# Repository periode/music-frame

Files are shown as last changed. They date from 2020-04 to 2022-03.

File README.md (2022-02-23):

# music frame

endless music box. wip.

## intent

it is a generative sonic atmosphere contained in a wooden frame.

it is slightly smaller than an A3 piece of paper, and it consists of a a small computer, a switch, and a speaker. the switch turns on the computer, the computer starts generating an ever-evolving version of a musical composition, and the speaker emits vibrations from the wood to fill the room with a soundscape. compositions are each conceived as a generative system, specifically for pogłos. they intend to live in the background of our lives, setting an atmosphere, decorating our sonic environment.

view some of the compositions live at [periode.github.io/music-frame]([https://periode.github.io/music-frame)

## thoughts and influences

the compsitions:

- erik satie's [vexations](https://en.wikipedia.org/wiki/Vexations), for the ability to repeat the same motif without boredom
- brian eno's generative music (made with [Koan](https://www.wired.com/1997/10/can-generative-music-carry-the-nets-tunes/), now rebranded as [Wotja](https://intermorphic.com/wotja/)), for the technical contribution
- [listen to wikipedia](http://listen.hatnote.com/), for the possible data visualization

the objects:

- [buddha machine](https://www.youtube.com/watch?v=VlSM3GMuYVU), for the product design
- [brand new noise](https://www.brandnewnoise.com/), for the product design (without the interaction/instrument aspect)

the polish word **pogłos** (pronounced *pog-wo-ss*)

1. an acoustic phenomenon consisting in the prolongation of sound, caused by the action of reflected waves in  a closed room
2. a multiplication of sound
3. a reference to something, especially in someone's work

## overview

- dimensions: 420mm \* 260mm \* 8mm
- weight: 1.2kg
- computer: raspberry pi zero w
- power supply: 5.1V / 2.5A
- speaker: dayton 3W 4Ohm exciter
- amplifier: adafruit speaker bonnet
- mount material: cnc wooden frame with linseed oil finish and acrylic cover

see [hardware](hardware/README.md) and [software](software/README.md)for more details

## images

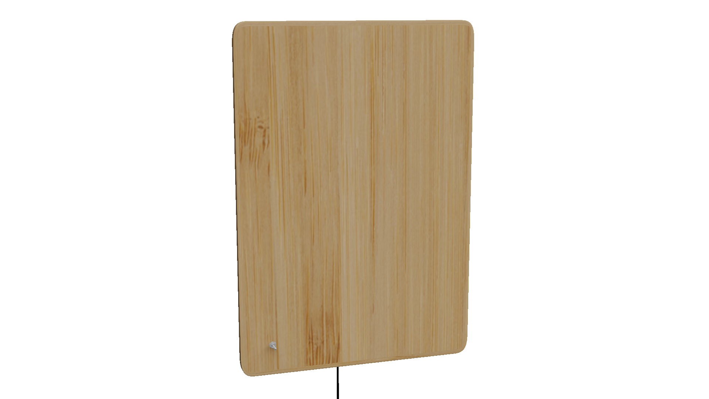
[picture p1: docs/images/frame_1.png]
front view of the panel

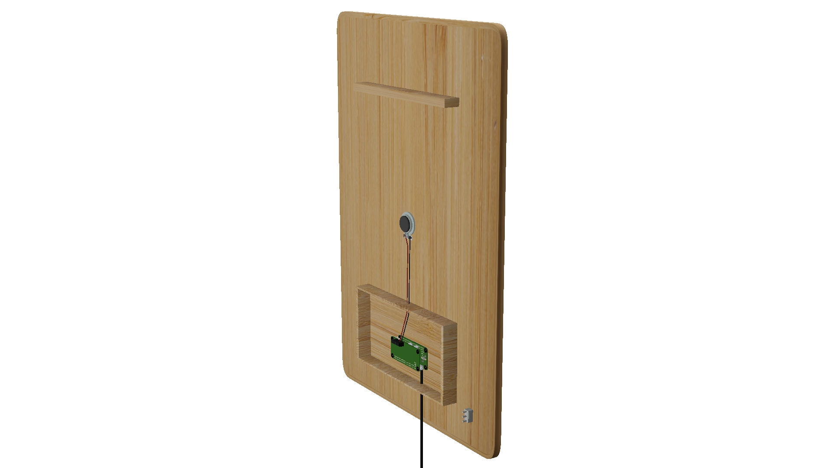
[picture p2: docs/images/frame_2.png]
back view of the panel


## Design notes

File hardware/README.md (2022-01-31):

# hardware

## electronics

the computer used is a [raspberry pi zero w 2](https://www.raspberrypi.com/products/raspberry-pi-zero-2-w/).

the audio exciters is a [dayton - DAEX13CT-4](https://www.variant-hifi.de/produkt/exciters/dayton-audio-daex13ct4-1416.html), with 4 Ohm [impedance](http://www.learningaboutelectronics.com/Articles/What-is-speaker-impedance) and 3 W RMS output - since the amp only provides 3W, having with significantly more watts (e.g. 10) doesn't make an audible difference.

connecting the computer and the output device is the [adafruit stereo speaker bonnet](https://www.adafruit.com/product/3346), both a DAC and amplifier, providing 3W output.

### alternatives

- battery version: [pisugar2](https://www.tindie.com/products/pisugar/pisugar2-battery-for-raspberry-pi-zero/)
- raspi amp: [hifiberry miniamp](https://www.hifiberry.com/shop/boards/miniamp/)
- raspi amp: [audio shim amp](https://thepihut.com/collections/raspberry-pi-audio-hats/products/audio-amp-shim-3w-mono-amp)
- controller: [arduino nano](https://www.ebay.de/itm/Nano-ATmega-328-Board-CH340-USB-Chip-Arduino-Kompatibel/252742123829) - 4.95
- arduino amplifier: [lm386 module](https://www.ebay.de/itm/Nano-ATmega-328-Board-CH340-USB-Chip-Arduino-Kompatibel/252742123829) - 2.95
- arduino storage: [sd card module](https://www.ebay.de/itm/Nano-ATmega-328-Board-CH340-USB-Chip-Arduino-Kompatibel/252742123829) - 3.50
- arduino integrated sd + dac: [yx5300](https://www.ebay.de/itm/YX5300-MP3-Musik-Player-Modul-Serial-UART-TTL-Module-Arduino-Raspberry-YX6300/253998552373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)
- esp32 board: [wemos pro](https://docs.wemos.cc/en/latest/d32/d32_pro.html)

## board

### frame

the frame is made both of __8mm plywood__ and __2.5mm acrylic__. the 8mm wood thickness is better for bass response and resists better to warping (6mm warps easily, and 10mm might sound a bit more muffled). the acrylic is used to cover the back of the frame.

the dimensions of the front board iare 420mm \* 260mm \* 8mm.

one suggested finish is pickling (brown or white) as a base layer and linseed oil as a top layer.

### cad

the most recent CAD (fusion) file can be found [here](models/poglos_main_board_20211121.f3d).

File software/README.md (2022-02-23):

# software

## setup

hw: raspberry pi zero 2
os: raspbian buster lite

- python version: 3.7+
- `pip install -r requirements.txt`
- file playback
  - [pygame](https://www.pygame.org)

[how to make python3 default](https://stackoverflow.com/questions/62275714/how-to-change-the-default-python-version-in-raspberry-pi)

- `sudo ln -s /usr/bin/pip3 /usr/bin/pip`
- `sudo rm /usr/bin/python && sudo ln -s /usr/bin/python3 /usr/bin/python`

## documentation

hostname: frame

username: pi
password: raspberry

### access point

[rogue ap](https://github.com/jerryryle/rogue_ap) was preferred

other research:

- [https://github.com/gitbls/autoAP]
- [https://github.com/balena-os/wifi-connect]
- [https://github.com/rudiratlos/hotspot]
- [https://www.raspberryconnect.com/projects/65-raspberrypi-hotspot-accesspoints/158-raspberry-pi-auto-wifi-hotspot-switch-direct-connection]
- [https://raspberrypi.stackexchange.com/questions/93311/switch-between-wifi-client-and-access-point-without-reboot]

## audio

the ideal is to share directly the project file (for instance, `.als` for ableton live, `.maxpat` for max, any source for programming environments), along with all samples used.

## instructions.yml

there is a config at the top of each track directory:

- mode
  - numeric: a given range of seconds to wait between two tracks
  - measure: a given range of proportions of the track length (0, 0.25, 0.5, 0.75, 1)
  - markov

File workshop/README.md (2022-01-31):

# sound sculpture workshop
===================================

## description
----------------------------

with all the music in the world at the end of our streaming fingertips, it's sometimes hard to think of sounds as something which takes up *space*, something with *weight*, something that can be *built*. and yet, affordable electronics, simple software and cnc machines make it easier than ever to design and construct a musical artefact.

this workshop takes the (very good) excuse of making such a musical artefact to learn the basics of software, hardware, parametric fabrication and sound design, over the course of two days. housed in the zonoteka gallery in neukolln, we will go through all the different steps involved in constructing your own sonified object.

the **electronics** part will include learning the basics of arduino, a hardware prototyping platform, how to connect together a micro-controller, a storage module, an amplifier and an audio exciter. the **software** part will get you introduced to the basics of programming the arduino, in order to program your own playback logic (or, as brian eno would put it, "semi-autonomous generative music"). the **fabrication** component will consist in learning how to design parts on vector software such as illustrator, and how to cut the casing of your object with zonoteka's CNC milling machines, and learning how such a design can arise from programming shapes with parameters, for a unique result. finally, the **sound design** of our object will introduce you to the nitty gritty of audio file formats, and to the craft of writing code to arrange and compose musical sections.

## schedule

----------------------------

pierre - mate - benjamin - andrea

- 10:00
  - welcome, introductions
  - presentation of the day
  - different possibilities
    - product design
    - sound design
    - composition
  
- 10:30
  - writing the code
  - soldering

- 11:30
  - designing the sound
  - recording and editing in audacity

- 12:30
  - break

- 13:30
  - designing the sculpture
  - illustrator/inkscape

- 14:30
  - fabrication
    - foam cutting
    - woodboard assembly
    - painting

## outcomes

- everyone (5 people) was able to finish a build
- no time to paint/coat
- only one cut on the foam machine
- no time to think about / write algorithmic composition
- next time needs a step-up module
- having board to test out soldering was good (also soldering from the reverse side)
- having more examples/several finished versions (both of music and cutouts would be good to give more ideas to the participants)

===================================

## hardware

the speaker used for now is the [dayton audio daex25fhe-4](https://www.soundimports.eu/en/dayton-audio-daex25fhe-4.html), with:

- 4 Ohm [impedance](http://www.learningaboutelectronics.com/Articles/What-is-speaker-impedance)
- 24 W RMS output

size of the mounted surface: approx 12x8cm, voltage sent: between 5V and 12V

## software

- file constraints
- - uncompressed (PCM / WAV)
- - 8-bit
- - 8-32Khz
- - mono
- SD card storage (16-64Gb)
- library used for playing back files: [TMRpcm](https://github.com/TMRh20/TMRpcm/wiki)

- library for composition: [less concepts](https://maxforlive.com/library/device/6167/less-concepts)

- how to

calculating time of each sample:

```C++
// from https://github.com/TMRh20/TMRpcm/issues/141
void loop(){  

  if(Serial.available()){    
    if(Serial.read() == 'p'){ //send the letter p over the serial monitor to start playback
      uint32_t sampleRate = 0;
      uint32_t fileSize = 0;
      float lengthInSeconds = 0.00;
      myFile = SD.open("calibrat.wav");      
      if(myFile){
        Serial.println("SD is open");
        myFile.seek(24);
        sampleRate = myFile.read();
        sampleRate |= (uint32_t)(myFile.read() << 8);
        sampleRate |= (uint32_t)(myFile.read() << 16);
        sampleRate |= (uint32_t)(myFile.read() << 24);
        fileSize = myFile.size()-44;
        lengthInSeconds = (float)(fileSize) / (float)(sampleRate) ;
        myFile.close();
        
      }else{
        Serial.println("cant open sd");
      }
      Serial.print("Length ");
      Serial.println(lengthInSeconds);
      tmrpcm.play("calibrat.wav");
    }
  }
}
```

## mood

[satoshi ashikawa - still way](https://www.youtube.com/watch?v=f33pvpdXzos) can loop forever
[taku sugimoto](https://www.youtube.com/watch?v=pDUeojq6DrE) - microtonal

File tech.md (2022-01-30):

# tech

## hardware

### main

- exciters:
- - [dayton exciter - DAEX25CT-4](https://www.variant-hifi.de/produkt/exciters/dayton-audio-daex25ct4-1422.html) / 11.50e 10W
- - 4 Ohm [impedance](http://www.learningaboutelectronics.com/Articles/What-is-speaker-impedance)
- - 3 W RMS output
- amp: 
- [hifiberry miniamp](https://www.hifiberry.com/shop/boards/miniamp/)
- [adafruit stereo speaker bonnet](https://www.adafruit.com/product/3346) - cheaper and smaller

size of the mounted surface: approx 50x35cm, voltage sent: between 5V and 12V

### software

- python version: 3.7+
- `pip install -r requirements.txt`
<<<<<<< HEAD
=======
- - mutagen: get track duration
>>>>>>> 177918da9734fe93ae2b81b9514a5c762a71b34f
- file playback
  - [pygame](https://www.pygame.org)

[how to make python3 default](https://stackoverflow.com/questions/62275714/how-to-change-the-default-python-version-in-raspberry-pi)

- `sudo ln -s /usr/bin/pip3 /usr/bin/pip`
- `sudo rm /usr/bin/python && sudo ln -s /usr/bin/python3 /usr/bin/python`

<<<<<<< HEAD
#### access point

- [https://github.com/gitbls/autoAP]
- [https://github.com/balena-os/wifi-connect]
- [https://github.com/rudiratlos/hotspot]
- [https://www.raspberryconnect.com/projects/65-raspberrypi-hotspot-accesspoints/158-raspberry-pi-auto-wifi-hotspot-switch-direct-connection]
- [https://raspberrypi.stackexchange.com/questions/93311/switch-between-wifi-client-and-access-point-without-reboot]

=======
>>>>>>> 177918da9734fe93ae2b81b9514a5c762a71b34f
### alternative

- battery version: [pisugar2](https://www.tindie.com/products/pisugar/pisugar2-battery-for-raspberry-pi-zero/)
- raspi amp: [audio shim amp](https://thepihut.com/collections/raspberry-pi-audio-hats/products/audio-amp-shim-3w-mono-amp)
- controller: [arduino nano](https://www.ebay.de/itm/Nano-ATmega-328-Board-CH340-USB-Chip-Arduino-Kompatibel/252742123829) - 4.95
- amplifier: [lm386 module](https://www.ebay.de/itm/Nano-ATmega-328-Board-CH340-USB-Chip-Arduino-Kompatibel/252742123829) - 2.95
- storage: [sd card module](https://www.ebay.de/itm/Nano-ATmega-328-Board-CH340-USB-Chip-Arduino-Kompatibel/252742123829) - 3.50
- voltage step-up: to find
- integrated sd + dac: [yx5300](https://www.ebay.de/itm/YX5300-MP3-Musik-Player-Modul-Serial-UART-TTL-Module-Arduino-Raspberry-YX6300/253998552373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)
- esp32 board: [wemos pro](https://docs.wemos.cc/en/latest/d32/d32_pro.html)

### arduino software

- playback of WAV files from SD Card: [TMRpcm](https://github.com/TMRh20/TMRpcm)

## notes

- issue with software volume control?
  - https://www.hifiberry.com/docs/hifiberryos/hifiberryos-how-to-control-playback/ (making a rotary volume control)

## cnc

- baud rate should be set to 115200 (on mac)
- modelled on blender

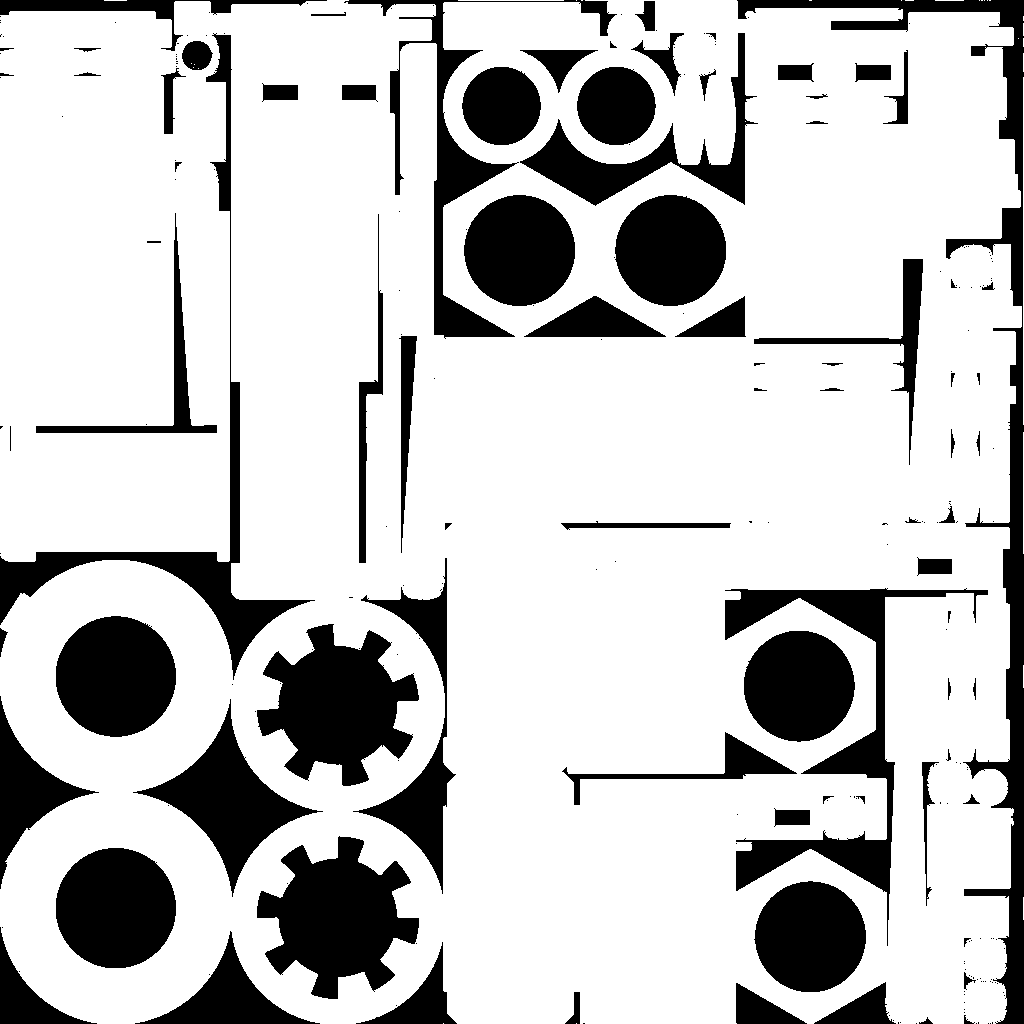
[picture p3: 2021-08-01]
hardware/models/switch.png

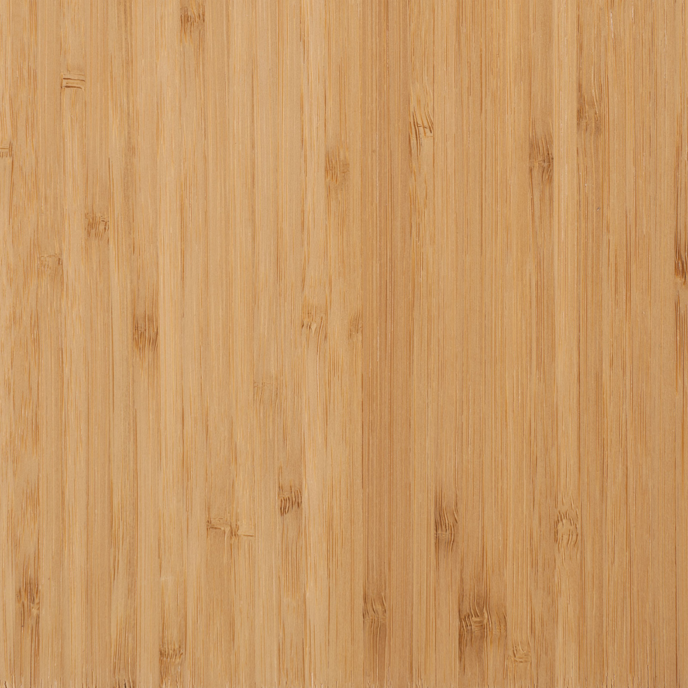
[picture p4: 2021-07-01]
hardware/models/wood.jpg

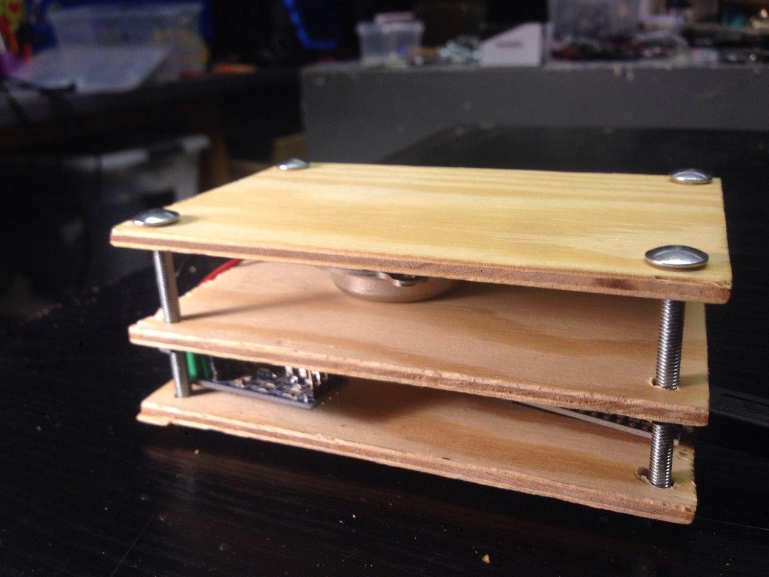
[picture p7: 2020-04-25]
workshop/media/20200308_proto_02.jpg

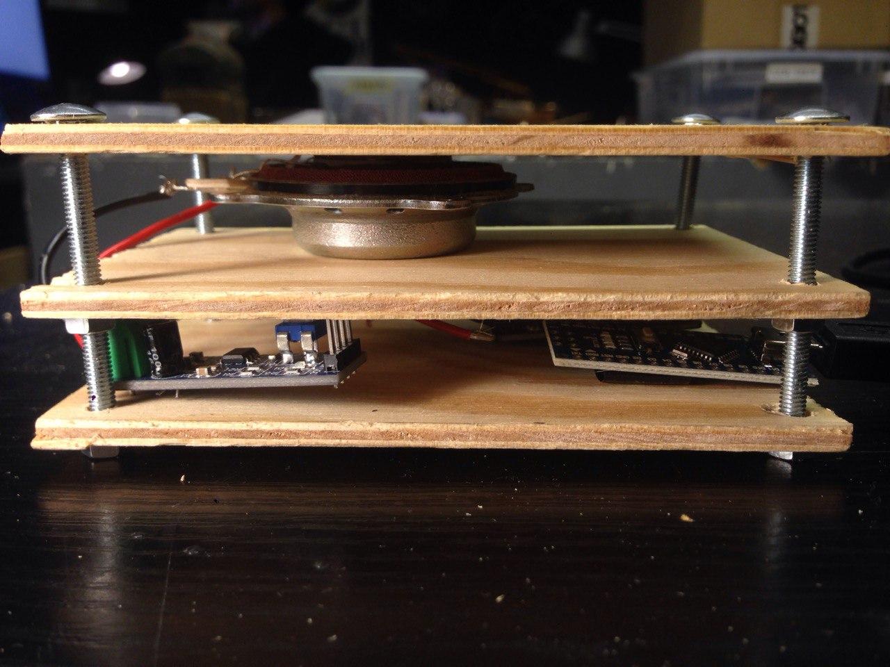
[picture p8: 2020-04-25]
workshop/media/20200308_proto_03.jpg

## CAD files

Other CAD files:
hardware/models/poglos_main_board_211121.f3d
hardware/models/poglos_main_board_290921.f3d

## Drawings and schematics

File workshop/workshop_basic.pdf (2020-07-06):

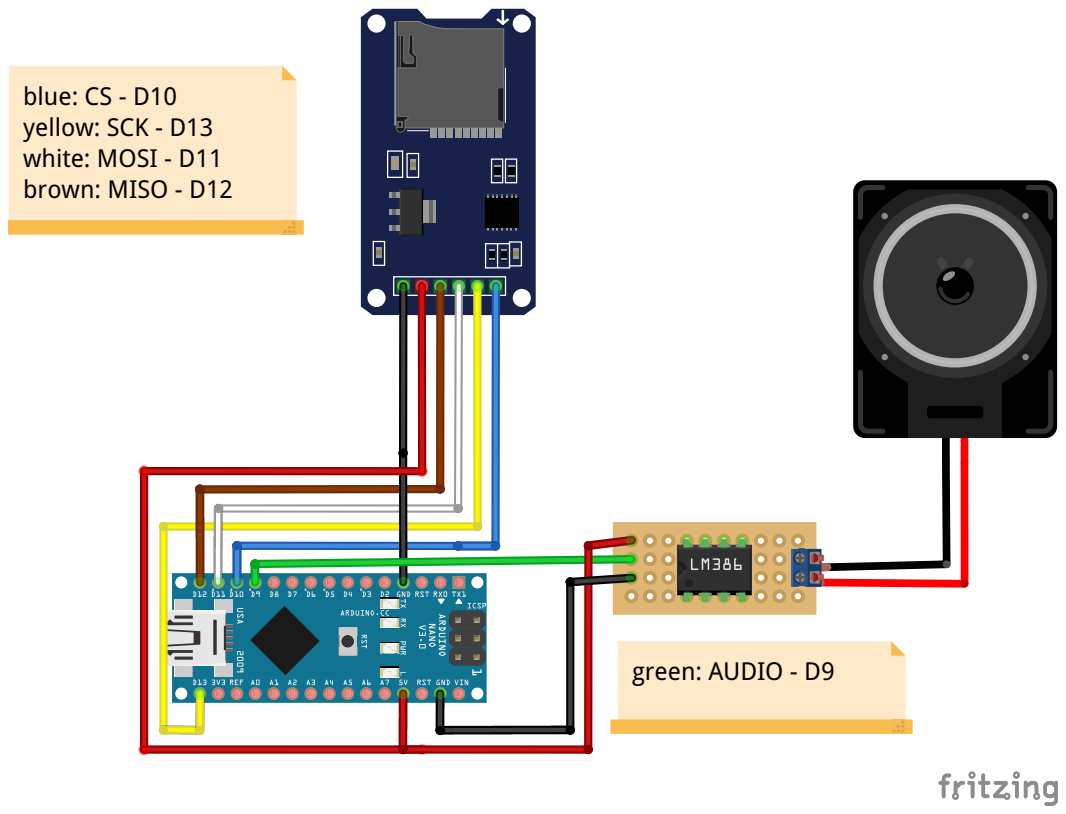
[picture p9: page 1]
blue: CS - D10 yellow: SCK - D13 white: MOSI - D11 brown: MISO - D12; green: AUDIO - D9

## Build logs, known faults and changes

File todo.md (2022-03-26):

# todo

## bugfix

- [x] on raw install on top of previous install, `systemctl reload apache2` returns "ERROR: Site android does not exist!" -> needed to rebuild

## features

- [x] name, consider music frame, with hexagrams (53 jian development, 56 lu wanderer) for different models
- [x] web interface for composition and communication
  - [x] switch from labelling as technique to labelling as compositions (swirl, gabor, vexations)
  - [x] layout
  - [x] random
  - [x] polyphonic
  - [x] add references
  - [x] deliver audio files through `static.enframed.net`
  - [x] DIY version
    - [x] add a ddl to a `.img`
- [x] power supply
  - [x] connect power supply
    - [x] glue it
    - [x] double sided tape on raspi
  - [x] connect front switch
- [ ] consider a version with a hardware interface for the buttons
- [x] frame design
  - [ ] v2
    - [x] update board to around A3 dimensions
    - [x] check the thickness of acrylic -> 2.5mm
    - [x] check if the electronics stack can fit below 2cm (total enclosure height would be 2.2cm) -> height is 1.7cm
    - [ ] think about mount for front switch, with power on/power off engravings
    - [ ] cut it!
  - [x] drawing
  - [x] basic frame in blender
  - [x] support both standing and hanging
    - [x] possibility for table-like
  - [x] rough modeling in blender
  - [x] details in fusion
- [x] controller
  - [x] network setup
  - [x] software volume control
    - [x] [using softvol 1](https://bytesnbits.co.uk/raspberry-pi-i2s-sound-output/)
    - [x] [using softvol 2](https://github.com/pimoroni/pirate-audio/issues/32) (`mplayer file -af volume=1`)
    - [x] pygame
  - [ ] stress test
    - [ ] bug: if I play a composition, and then refresh the page, the composition is not updated
    - [ ] bug: deal properly with stopping the sound (given that there are two buttons, digital and physical -> maybe have the digital use the `is_playing` attribute?)
    - [x] CPU usage goes up to 180%: change the amount of time waiting in main thread? change the memory split between GPU and CPU? -> 16MB
  - [x] local web interface
- [ ] code
  - [ ] make the hardware interface its own module
    - [x] modularize
    - [ ] think about message queuing/passing system, which would also enable a server module
  - [x] added debug mode
  - [x] add cute output: for each track pick a single character to print on the terminal (e.g. . - * ^) - memory leak
  - [x] make `run_event` and `threads` member fields of `Composition`
  - [x] check pygame playback on raspi
    - [x] fix `ALSA lib pcm.c:8545:(snd_pcm_recover) underrun occurred` error [src](https://forums.adafruit.com/viewtopic.php?f=19&t=175237&p=858042) -> nope, trying to have all files as WAV?
  - [x] move all binaries to pygame
  - [x] check bug on swirl where some files are not found - explicitly set filenames to null in composition init
  - [x] apache server
    - [x] running on arch
    - [x] running on pi
    - [x] captive portal
    - [x] check the restore-wifi script
    - [x] add a command to download all files in the install script.
    - [x] issue with the "gstatic.connectivitycheck" on android -> check [this](https://rachitpandya.medium.com/how-to-create-a-captive-portal-38aba6284b91)
      - [ ] consider other android virtual hosts as well
    - [x] [this one](https://github.com/jerryryle/rogue_ap/blob/main/setup.sh) with modifications:
      - do not copy files over for the python wsgi app
      - change the apache config file to specify `ServerName frame.here`
      - delete some of the python wsgi modules in the apache conf
      - add an iptables rule for ssh connection: `-A PREROUTING -i br0 -p tcp -m tcp --dport 22 -j DNAT --to-destination 10.1.1.1:22`
    - [x] adapt all files and configs from the repo
  - [x] connect with the flask API
    - [x] consider sockets
    - [x] add logging
    - [ ] design
      - [x] typography rather than colors
      - [ ] logo should be unique (echo with the logo carved on the board with the cnc)
      - [ ] should we always see what is playing? should it be on a separate view?
        - [ ] if it's on a separate view, there is room for generative graphics!
        - [ ] what kind of headspace do i want the user to be in?
    - [x] make the server run on its own thread
    - [x] list available compositions
    - [x] start compositions
    - [x] stop compositions
    - [x] volume control
    - [x] save/load preferences
    - [x] reactive layout
    - [x] volume slider
    - [x] finish help text
    - [x] make a "loading" display while the composition loads
  - [x] pygame playback
    - [x] make lfo for volume
  - [x] make each playmode into classes
    - [x] make the data structure
    - [x] implement delay offsets through composition instruction config file
  - [x] threads
    - [x] research
    - [x] figure out how to cleanly close the threads (based on [this](https://stackoverflow.com/questions/41961430/how-to-cleanly-kill-subprocesses-in-python))
  - [x] use a player which supports mp3
    - [x] using `play` on arch
    - [x] check on raspi
      - [x] had to use mplayer
    - [x] have an args list for each player (e.g. quiet or not)
  - [x] test on raspberry pi

## notes

background music as an artwork.

it's about the surprise, the unexpected that comes out of the expected. the thing you know, and forgot you were aware of. it's about turning on the music the same way you turn on your favorite light on a coloured spot of the room. maybe like a musical plant.

questions of timing, of spacing, of silence. questions of repetition and resolution (how often does it resolve? does it ever resolve, like [this](https://www.youtube.com/watch?v=IE8gISNPz7I)?). carl stone made [elastic](https://www.youtube.com/watch?v=X-OHTj4xcgg) (hence symmetrical?) music.

[laurie spiegel on musical manipulation](http://www.retiary.org/ls/writings/musical_manip.html):  shift / reverse / rescale / interpolate / corrupt

[laurie spiegel - noise in composition](http://retiary.org/ls/writings/info_theory_music.html)

- different modes? (morning, afternoon, night)
- one long-ass soundscape vs. recombinating segments
- how much user control? volume, which composition, but all the way to changing parameters?

for conversion: `ffmpeg-normalize *.wav -ext mp3 -t -5 -c:a libmp3lame -t .`

names:

- sound board
- timbre
- sonancy
- assonance

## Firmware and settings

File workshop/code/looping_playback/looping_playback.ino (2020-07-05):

#include <pcmConfig.h>
#include <TMRpcm.h>

#include <SD.h>
#define SD_ChipSelectPin 10    //-- using digital pin 4 on arduino nano 328, can use other pins
#include <SPI.h>

TMRpcm player;

String[] tracks = {"file1.wav", "file2.wav", "file3.wav"};
int totalNumberOfTracks = 3;

void setup(){

  player.speakerPin = 9; //--5,6,11 or 46 on Mega, 9 on Uno, Nano, etc

  Serial.begin(9600);
  
  if (!SD.begin(SD_ChipSelectPin)) {  //-- first things first, check if the card works
    Serial.println("SD fail");  
    return;                           //-- if not, don't do anything more
  }

  Serial.println("SD Success");

  player.setVolume(5);      //-- for obscure reasons, 7 is the maximum value. beyond 7, you get distortion
  player.loop(1);           //-- this enables loop mode
  player.play("bullion.wav"); //-- the sound file "file1.wav" will play each time the arduino powers up, or is reset

}



void loop(){  

  if(!player.isPlaying()){ //-- once we're done playing the track
    
    //-- choose the track to play, randomly
    int trackIndex = (int)(random(0, totalNumberOfTracks));

    player.play(tracks[trackIndex]);


    /*
    //-- pick the following track on the list
    trackIndex++;
    if(trackIndex == totalNumberOfTracks){
      trackIndex = 0;
    }

    player.play(tracks[trackIndex]);

    */
  }
  
}

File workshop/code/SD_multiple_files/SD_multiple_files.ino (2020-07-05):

#include <SD.h>                      // need to include the SD library
#define SD_ChipSelectPin 10  //using digital pin 4 on arduino nano 328, can use other pins
#include <SPI.h>

#define NUMBER_OF_SAMPLES 3
String files[NUMBER_OF_SAMPLES] = {"first.wav", "second.wav", "third.wav"};
float durations[NUMBER_OF_SAMPLES] = {8500, 8730, 9290};
int current_file = 0;

float startTime = 0;

void setup() {

  Serial.begin(9600);
  if (!SD.begin(SD_ChipSelectPin)) {  // see if the card is present and can be initialized:
    Serial.println("SD fail");
    return;   // don't do anything more if not
  }

  Serial.println("SD success!");
}

void loop() {
  if(millis() - startTime > durations[current_file]){
    Serial.print("Finished playing ");
    Serial.println(files[current_file]);

    Serial.println("---");

    Serial.print("Picking next file ");
    current_file = (int)(random(0, 3));
    Serial.print(files[current_file]);
    Serial.print(" - ");
    Serial.println(durations[current_file]);
    
    
    startTime = millis();
  }
}

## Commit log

2020-04-25 updated all notes
    [LM386.fzz, layout_1.fzz]
2020-07-06 added modifications post-workshop
    [layout_1.fzz]
2021-06-29 switched to raspberry pi as main platform
    [LM386.fzz, layout_1.fzz]
2021-07-01 added frame model
2021-08-01 added basic playback for two modes in python script; added swirl samples for polyphonic demo
2021-08-02 added working threads on both compositions
2021-09-01 switched to mplayer on raspi
2022-01-09 straight 8mm
2022-01-09 added updated board designs
    [poglos_main_board 211121.f3d, poglos_main_board_290921.f3d]
2022-01-11 added gabor as part of main script and switched all playback to pygame
2022-01-16 added volume control, preferences, fixed a bug on starting a new composition and track file discovery
2022-01-31 reorganized repo
    [LM386.fzz, layout_1.fzz, poglos_main_board 211121.f3d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]
2022-01-31 updated main and hardware readme
    [poglos_main_board_211121.f3d]
2022-02-19 uploaded image copy and glued all frame together
2022-02-19 added button control
2022-02-23 renamed poglos to music frame
2022-02-23 renamed from poglos to music frame
2022-02-24 added broker.py for sockets and refactored composition
